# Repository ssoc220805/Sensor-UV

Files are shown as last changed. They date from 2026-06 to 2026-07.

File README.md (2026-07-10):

# Centinela UV — Sistema de Monitoreo de Radiación Ultravioleta

Centinela UV es un dispositivo IoT basado en **ESP32-S3** y sensor **GY-ML8511** que mide la radiación ultravioleta, avisa el nivel de riesgo con un **LED RGB**, envía cada lectura a un **servidor web en Hostinger** donde queda guardada, y manda una **alerta por Telegram** cuando el índice UV sube a un nivel peligroso.

Proyecto desarrollado para el curso **TEI201 — Taller de Diseño en Ingeniería**, Universidad Adolfo Ibáñez.

---

## Integrantes

- Leo Castro
- Sara Orellana
- Cristian Yañez

---

## El problema

Las personas que pasan tiempo al aire libre no tienen una forma directa de saber qué tan intensa es la radiación ultravioleta a la que están expuestas, ni cuándo deberían protegerse. La información disponible suele ser general (el pronóstico de la ciudad) y no refleja las condiciones del lugar exacto donde está la persona.

Centinela UV entrega una medición local y en tiempo real de la radiación UV, junto con una recomendación clara de protección según el nivel detectado.

---

## Qué hace el sistema

El sistema cumple el ciclo completo de un dispositivo IoT:

1. **Captura.** El sensor GY-ML8511 entrega un voltaje proporcional a la radiación UV. El ESP32-S3 lo lee con su conversor analógico-digital y lo transforma en un índice UV.
2. **Almacena.** Cada 3 segundos el ESP32 envía la lectura por WiFi a un script `guardar.php` alojado en Hostinger, que la guarda de forma permanente. Los datos siguen ahí aunque el dispositivo se apague.
3. **Visualiza.** El dashboard web muestra el índice UV actual, la recomendación de protección y el resumen del día (máximo, mínimo y promedio) con un gráfico.
   → https://lightskyblue-zebra-707371.hostingersite.com/
4. **Decide.** El LED RGB cambia de color según el nivel de riesgo, y si el índice supera el umbral el sistema **manda una alerta a Telegram** para que el usuario se entere aunque no esté mirando ni el dispositivo ni la página.

---

## Arquitectura

```
Sensor GY-ML8511  →  ESP32-S3  →  WiFi  →  Hostinger (guardar.php)  →  Dashboard web
                          │
                          ├──→  LED RGB (aviso local inmediato)
                          └──→  API de Telegram (alerta al celular)
```

El ESP32 se conecta a una red WiFi existente (durante las pruebas usamos el hotspot de un celular). No sirve la página web por sí mismo: la página está alojada en Hostinger, y por eso se puede abrir desde cualquier lugar con internet, no solo estando al lado del dispositivo.

---

## Niveles de riesgo

El firmware clasifica el índice UV en tres niveles:

| Índice UV | Nivel | Color del LED | Alerta Telegram | Recomendación |
|---|---|---|---|---|
| 0.0 – 2.9 | BAJO | Verde | No | No se requiere protección especial |
| 3.0 – 5.9 | MODERADO | Amarillo | Aviso | Usar bloqueador y lentes de sol |
| 6.0 o más | ALTO | Rojo | Alerta | Buscar sombra, usar bloqueador, sombrero y lentes |

Los cortes en 3 y 6 vienen de la tabla oficial del Índice UV de la OMS. Agrupamos las categorías "alto", "muy alto" y "extremo" en un solo nivel ALTO porque la acción recomendada para el usuario es la misma: protegerse.

Para no llenar de mensajes el celular, el sistema solo envía una alerta **cuando el nivel cambia** (por ejemplo, de BAJO a MODERADO) y respeta un tiempo de espera entre alertas del mismo tipo.

---

## Componentes

| Componente | Cantidad | Especificación | Función |
|---|---|---|---|
| ESP32-S3 DevKitC-1 | 1 | WiFi 2.4 GHz, doble núcleo | Lee el sensor, controla el LED y envía los datos |
| Sensor UV GY-ML8511 | 1 | Salida analógica, 280–390 nm | Medición de radiación ultravioleta |
| LED RGB | 1 | Cátodo común, 5 mm | Indicación visual del nivel de riesgo |
| Resistencias | 3 | 220 Ω, 1/4 W | Limitan la corriente de cada canal del LED |
| Batería LiPo | 1 | 3.7 V, ~1200 mAh | Alimentación autónoma |
| Controlador Li-Po Rider Pro | 1 | Carga solar/USB, salida 5 V | Gestiona la carga y alimenta el ESP32 |
| Panel solar | 1 | 5 V, ~1 W | Recarga la batería |
| Mini protoboard | 1 | — | Montaje sin soldar |
| Cables Dupont | 1 set | 20 cm | Conexiones |

El detalle con costos está en [`hardware/Documentacion_Hardware.md`](hardware/Documentacion_Hardware.md).

---

## Conexiones

| Señal | Pin del ESP32-S3 | Nota |
|---|---|---|
| Sensor UV — VCC | 3.3 V | Alimentación del sensor |
| Sensor UV — GND | GND | Tierra común |
| Sensor UV — OUT | **GPIO4** | Entrada analógica (ADC1) |
| LED Rojo | **GPIO40** | Con resistencia de 220 Ω |
| LED Verde | **GPIO39** | Con resistencia de 220 Ω |
| LED Azul | **GPIO38** | Con resistencia de 220 Ω |
| LED — pata común | GND | LED de cátodo común |
| Batería LiPo | Li-Po Rider Pro (BAT) | Conector JST |
| Panel solar | Li-Po Rider Pro (SOLAR) | Entrada de carga solar |
| Li-Po Rider Pro — salida 5 V | VIN del ESP32-S3 | Alimenta todo el sistema |

Estos son los pines que usa el código en `firmware/centinela_uv2.ino`. La tabla, el esquemático y el código dicen lo mismo.

---

## Estructura del repositorio

```
centinela-uv-tei201/
├── README.md
├── FUENTES.md
├── .gitignore
├── firmware/
│   ├── centinela_uv2.ino          Código del ESP32
│   └── config_ejemplo.h           Plantilla de credenciales (sin claves reales)
├── backend/
│   ├── guardar.php                Recibe y guarda cada lectura
│   ├── test.php                   Activa el modo demostración
│   └── index.html                 Dashboard web
├── hardware/
│   ├── Documentacion_Hardware.md
│   ├── esquematico.png
│   └── fotos/
├── diseño-3d/
│   ├── Modelado_3D_rehechov2.f3d
│   ├── soporte__defin_.f3d
│   ├── planos.pdf
│   └── renders/
├── testing/
│   ├── Protocolo_de_pruebas.md
│   ├── Resultados.md
│   ├── datos/lecturas_23-06-2026.csv
│   └── evidencia/                 Capturas del bot de Telegram y del dashboard
└── docs/
    └── presentacion.pdf
```

---

## Cómo cargar el firmware

1. Instalar el [Arduino IDE](https://www.arduino.cc/en/software) y agregar el soporte para placas ESP32 desde el Gestor de Tarjetas.
2. Abrir `firmware/centinela_uv2.ino`.
3. En **Herramientas → Placa**, seleccionar **ESP32S3 Dev Module**.
4. Crear un archivo `config.h` a partir de `config_ejemplo.h` y completar la red WiFi, la clave de la API y las credenciales del bot de Telegram.
5. Conectar la placa por USB, seleccionar el puerto y subir el código.
6. Abrir el Monitor Serial a **115200 baudios** para ver las lecturas y confirmar que la respuesta del servidor sea `200`.

El firmware usa `WiFi.h`, `WiFiClientSecure.h` y `HTTPClient.h`, que vienen incluidas con el núcleo de ESP32. No hay que instalar librerías externas.

### Sobre las credenciales

La red WiFi, la clave de la API y el token del bot de Telegram **no se suben al repositorio**. Van en `config.h`, que está listado en `.gitignore`. Si alguien publica un token de Telegram por accidente, hay que revocarlo de inmediato con @BotFather y generar uno nuevo.

---

## Cómo usar el dashboard

El dashboard está alojado en Hostinger, así que se abre desde cualquier navegador con internet: no hace falta estar cerca del dispositivo.

1. Encender el dispositivo y verificar que se conecte al WiFi (el Monitor Serial muestra la IP).
2. Abrir https://lightskyblue-zebra-707371.hostingersite.com/
3. La página muestra la última lectura, la recomendación de protección y el gráfico del día.

Las lecturas quedan guardadas en el servidor, así que el histórico sigue disponible aunque el ESP32 se apague o se reinicie.

---

## Alertas de Telegram

El bot **Centinela UV Bot** envía tres tipos de mensaje:

- `Sistema Monitor UV encendido.` — cada vez que el dispositivo arranca y logra conectarse.
- `Aviso: UV moderado. Indice X` — cuando el índice pasa de BAJO a MODERADO.
- `ALERTA UV ALTO. Indice X` — cuando el índice llega al nivel ALTO.

Existe además un **modo demostración**: el ESP32 consulta cada 6 segundos un archivo `test.php` en el servidor, y si este devuelve `1`, el dispositivo fuerza el estado ALTO durante 8 segundos y manda el mensaje `PRUEBA: alerta de UV ALTO.`. Esto nos permite mostrar la alerta funcionando en la presentación sin depender de que haya sol. Los mensajes que empiezan con `PRUEBA:` corresponden a este modo, no a una medición real.

---

## Limitaciones conocidas

- La conversión de voltaje a índice UV usa la relación aproximada del ML8511 (0.99 V ≈ 0, 2.8 V ≈ 15). No fue calibrada contra un medidor UV de referencia, así que el valor absoluto puede tener error; lo que sí validamos es que el sensor responde correctamente a los cambios de luz.
- El firmware envía dos campos `temp` y `hum` que siempre valen 0, porque quedaron de una versión anterior del proyecto que contemplaba un sensor de temperatura. El sistema no mide temperatura ni humedad.
- El sistema necesita una red WiFi disponible. Si se cae la conexión, el dispositivo sigue midiendo y encendiendo el LED, pero no guarda ni alerta.

---

## Declaración de fuentes

El uso de librerías, código externo y herramientas de inteligencia artificial está documentado en [`FUENTES.md`](FUENTES.md), de acuerdo con el código de honor de la Universidad Adolfo Ibáñez.

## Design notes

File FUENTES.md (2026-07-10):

# Declaración de Fuentes e Inteligencia Artificial

Este documento declara las librerías, los servicios externos, el código externo y las herramientas de inteligencia artificial que usamos para desarrollar **Centinela UV**. La idea es ser transparentes sobre qué partes del trabajo se apoyaron en recursos externos y dejar claro que entendemos todo el código que forma parte del sistema, de acuerdo con el código de honor de la Universidad Adolfo Ibáñez.

Los números de línea corresponden al archivo `firmware/centinela_uv2.ino`.

---

## 1. Librerías utilizadas

| Librería | Versión | Para qué la usamos | Fuente |
|---|---|---|---|
| `WiFi.h` | core ESP32 `<completar>` | Conectar el ESP32-S3 a la red WiFi en modo estación (STA) | https://github.com/espressif/arduino-esp32 |
| `WiFiClientSecure.h` | core ESP32 `<completar>` | Abrir la conexión HTTPS hacia Hostinger y hacia la API de Telegram | https://github.com/espressif/arduino-esp32 |
| `HTTPClient.h` | core ESP32 `<completar>` | Hacer las peticiones POST y GET al servidor y al bot | https://github.com/espressif/arduino-esp32 |

Las tres librerías vienen incluidas con el núcleo de ESP32 para Arduino, así que no fue necesario instalar nada aparte. La versión es la del núcleo instalado y se revisa en **Arduino IDE → Herramientas → Placa → Gestor de Tarjetas → esp32**.

> Nota para el equipo: completar los tres campos de versión antes de entregar.

---

## 2. Servicios externos utilizados

| Servicio | Para qué lo usamos |
|---|---|
| Hostinger (hosting PHP) | Aloja `guardar.php`, que recibe las lecturas y las almacena, y el dashboard web |
| API de Telegram Bot | Envía las alertas al celular cuando el índice UV sube de nivel |

---

## 3. Código externo adaptado

No copiamos código completo desde tutoriales, foros ni repositorios de otras personas. Usamos como referencia conceptual los ejemplos oficiales del núcleo de ESP32 para conexión WiFi y para peticiones HTTP, y la documentación de la API de Telegram para el formato de la URL de `sendMessage`:

- Ejemplos WiFi y HTTPClient: https://github.com/espressif/arduino-esp32/tree/master/libraries
- API de Telegram: https://core.telegram.org/bots/api#sendmessage

Las partes del código que no escribimos desde cero las desarrollamos con ayuda de inteligencia artificial, y están declaradas en la sección siguiente.

---

## 4. Uso de Inteligencia Artificial

### 4.1 Lectura del sensor: `leerUV()` (líneas 71–89)

- **Herramienta:** Claude (junio 2026).
- **Prompt utilizado:** "Escribe una función en C++ para Arduino que lea un sensor analógico ML8511 con el ADC del ESP32-S3 y convierta el voltaje en índice UV."
- **Cómo lo adaptamos:** cambiamos la lectura única por el promedio de 5 muestras seguidas con 1 ms de separación, para reducir el ruido del ADC. Ajustamos la conversión a la relación del GY-ML8511 (0.99 V ≈ índice 0, 2.8 V ≈ índice 15) y agregamos una saturación entre 0 y 20 para descartar valores imposibles.
- **Comprensión:** entendemos que `analogRead()` devuelve un número entre 0 y 4095 porque configuramos 12 bits de resolución; ese número se multiplica por `3.3/4095` para obtener el voltaje real del pin; y `mapFloat()` hace una interpolación lineal entre los dos puntos de referencia del sensor. Verificamos el comportamiento en el Monitor Serial tapando y destapando el sensor.

### 4.2 Control del LED RGB: `setColor()` y clasificación en el `loop()` (líneas 59–69 y 227–260)

- **Herramienta:** Claude y Gemini (junio 2026).
- **Para qué:** apoyo para escribir la función que enciende los tres canales del LED y la lógica que decide el color según el índice UV.
- **Cómo lo adaptamos:** definimos nosotros los cortes en 3.0 y 6.0 a partir de la tabla del Índice UV de la OMS, agrupando "alto", "muy alto" y "extremo" en un solo nivel ALTO. Agregamos la constante `ANODO_COMUN` para que la función sirva con LED de ánodo o de cátodo común (usamos cátodo común, `false`).
- **Comprensión:** entendemos que el LED se controla con tres salidas digitales independientes y que el color se forma combinándolas (verde = solo G, amarillo = R + G, rojo = solo R). Si el LED fuera de ánodo común, la lógica se invierte, y por eso la función niega los tres valores.

### 4.3 Envío de datos al servidor: `enviarDato()` (líneas 119–152)

- **Herramienta:** Claude (junio 2026).
- **Para qué:** apoyo para armar la petición HTTPS hacia el script `guardar.php` en Hostinger.
- **Cómo lo adaptamos:** definimos el formato del cuerpo (`key`, `uv`, `temp`, `hum`) para que coincidiera con lo que espera nuestro `guardar.php`, y agregamos una verificación de conexión WiFi que intenta reconectar antes de enviar.
- **Comprensión:** entendemos que se abre un cliente seguro, se envía la información como un formulario (`x-www-form-urlencoded`) mediante POST, y que el servidor responde con un código HTTP; el 200 confirma que el dato quedó guardado. Usamos `client.setInsecure()` porque no cargamos el certificado raíz en el ESP32; sabemos que eso significa que no se valida la identidad del servidor, y es una limitación aceptable para un prototipo académico.

### 4.4 Alertas de Telegram: `enviarTelegram()` (líneas 154–176) y la lógica de aviso en el `loop()` (líneas 261–277)

- **Herramienta:** Claude (junio 2026).
- **Prompt utilizado:** "Cómo enviar un mensaje desde un ESP32 a un bot de Telegram usando HTTPClient, sin librerías externas."
- **Cómo lo adaptamos:** reemplazamos los espacios y saltos de línea del mensaje por `%20` y `%0A` para que la URL sea válida. Sobre esa base, nosotros escribimos la lógica de cuándo alertar: el mensaje se manda **solo cuando el nivel cambia** (comparando `nivel` con `nivelAnterior`) y respetando un tiempo de espera (`COOLDOWN_TG`), para no llenar el chat de mensajes repetidos cuando el índice oscila alrededor de un umbral.
- **Comprensión:** entendemos que la API de Telegram recibe el token del bot y el `chat_id` dentro de la URL y devuelve un código HTTP; que `nivelAnterior` es lo que evita que se repita la alerta en cada ciclo del `loop`; y que el cooldown es una segunda protección para el caso en que el índice cruce el umbral varias veces seguidas.

### 4.5 Modo demostración: `revisarPrueba()` (líneas 178–200)

- **Herramienta:** Claude (junio 2026).
- **Para qué:** necesitábamos poder mostrar la alerta funcionando durante la presentación sin depender de que hubiera sol.
- **Cómo lo adaptamos:** el ESP32 consulta cada 6 segundos un archivo `test.php` del servidor; si devuelve `1`, guarda un tiempo límite en `pruebaHasta` y manda el mensaje `PRUEBA: alerta de UV ALTO.`. Durante los 8 segundos siguientes el `loop` fuerza el estado ALTO y el LED rojo.
- **Comprensión:** entendemos que esta función **no mide nada**: fuerza el estado. Por eso los mensajes que empiezan con `PRUEBA:` no corresponden a mediciones reales, y por eso en las capturas se ve un `ALERTA UV ALTO. Indice 0.0` justo después de una prueba: el nivel se forzó aunque el sensor estuviera leyendo 0. Lo declaramos explícitamente para no confundir simulación con medición.

### 4.6 Backend: `guardar.php`, `test.php` y dashboard `index.html`

- **Herramienta:** Claude (junio 2026).
- **Para qué:** generar el script PHP que recibe cada lectura y la guarda de forma persistente en el hosting, y la página web que muestra el valor actual, la recomendación de protección y el gráfico del día con máximo, mínimo y promedio.
- **Cómo lo adaptamos:** definimos la clave de API para que el servidor rechace peticiones que no vengan de nuestro dispositivo; mantuvimos los rangos y colores que definimos como equipo; y agregamos un modo de demostración en la página para poder mostrarla completa en la presentación.
- **Comprensión:** entendemos que el ESP32 hace un POST con los datos, el PHP los valida contra la clave y los agrega al registro, y la página lee ese registro para dibujar el gráfico y calcular los estadísticos del día.

### 4.7 Estructura del README y de este archivo

- **Herramienta:** Claude (junio 2026).
- **Para qué:** generar la estructura base de `README.md` y de este `FUENTES.md`.
- **Cómo lo adaptamos:** el contenido técnico (pines, niveles, decisiones de diseño, resultados de las pruebas) lo escribimos nosotros a partir del sistema que efectivamente construimos.

### 4.8 Orientación general del proyecto

- **Herramienta:** Claude y Gemini.
- **Para qué:** pedir orientación sobre cómo avanzar en el proyecto, la organización del repositorio y dudas puntuales durante el desarrollo.
- **Nota:** este apoyo fue de orientación al proceso. Las decisiones de diseño, la selección de componentes, el montaje físico y el contenido final del proyecto los definimos nosotros como grupo.

---

## 5. Declaración final

Declaramos que las herramientas externas y la inteligencia artificial se usaron como apoyo para acelerar el desarrollo, la depuración y la documentación. Las decisiones técnicas, la integración física, las pruebas y la adaptación al problema fueron realizadas por el equipo. Todos los integrantes podemos explicar qué hace cada función del código y por qué está donde está.

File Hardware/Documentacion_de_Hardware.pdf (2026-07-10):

## Documentación de Hardware — Centinela UV

TEI201 · Taller de Diseño en Ingeniería · Universidad Adolfo Ibáñez Leo Castro · Sara Orellana · Cristian Yañez

### 1. Descripción general

Centinela UV es un dispositivo portátil que mide la radiación ultravioleta y avisa el nivel de riesgo de tres formas: un LED RGB que cambia de color, una página web que muestra el valor y una recomendación, y una alerta por Telegram cuando el índice UV es alto.

Está pensado para usarse al aire libre. Por eso se alimenta con una batería recargable mediante un panel solar, y no necesita estar enchufado.

### 2. Selección y justificación de componentes

Elegimos cada componente pensando en que el dispositivo funcionara de forma autónoma al aire libre, fuera fácil de armar y se mantuviera barato.

Componente | Por qué lo elegimos
ESP32-S3 DevKitC-1 | Trae WiFi 2.4 GHz integrado, así podemos enviar los datos al servidor y las alertas a Telegram sin hardware adicional. Su ADC de 12 bits es suficiente para leer la salida analógica del sensor.
Sensor UV GY-ML8511 | Cubre el rango UVA/UVB (280–390 nm), que es el que afecta a la piel. Entrega una salida analógica lineal, fácil de leer con el ADC del ESP32. Es común y económico.
LED RGB (cátodo común) | Permite comunicar el nivel de riesgo con un color, de un vistazo, sin tener que mirar la pantalla ni el celular.
Resistencias 220 Ω | Limitan la corriente de cada canal del LED para que no se queme. Con 3.3 V y un LED de caída ~2 V, la corriente queda cerca de 6 mA por canal: suficiente brillo, bajo consumo.
Batería LiPo 3.7 V | Permite que el dispositivo funcione sin estar enchufado, que es la idea al usarlo al aire libre.
Controlador Li-Po Rider Pro | Maneja la carga de la batería desde el panel solar, protege la celda y entrega 5 V estables al ESP32. Sin él, conectar el panel directo a la batería sería inseguro.
Panel solar 5 V ~1 W | Recarga la batería con el sol. Como el dispositivo se usa justamente cuando hay sol, la fuente de energía coincide con el momento de uso.
Mini protoboard | Permite armar y cambiar conexiones sin soldar, lo que apoya el diseño para la reparación.
Cables Dupont | Conexiones desmontables entre el sensor, el LED y el ESP32.

### 3. Consumo y autonomía

Valores típicos de hoja de datos. Sirven para estimar la autonomía; conviene verificarlos con multímetro.

Elemento | Consumo típico
ESP32-S3 con WiFi activo | ~100 mA promedio (picos de hasta ~350 mA al transmitir)
Sensor GY-ML8511 | ~0,3 mA
LED RGB (1 canal encendido) | ~6 mA
Total estimado | ~110 mA promedio

Con una batería de 1200 mAh:

Autonomía ≈ 1200 mAh / 110 mA ≈ 11 horas de uso continuo

El panel solar de 1 W entrega aproximadamente 200 mA a 5 V con sol directo, es decir más de lo que consume el sistema. En condiciones de buena luz el panel alcanza para alimentar el dispositivo y además recargar la batería, que es exactamente el escenario de uso del proyecto.

### 4. Lista de materiales (BOM)

Componente | Cant. | Especificación | Precio unit. (CLP) | Subtotal (CLP)
ESP32-S3 DevKitC-1 | 1 | WiFi 2.4 GHz, doble núcleo | $14.990 | $14.990

Sensor UV GY-ML8511 | 1 | Analógico, 280–390 nm | $20.000 | $20.000
LED RGB | 1 | Cátodo común, 5 mm | $800 | $800
Resistencia 220 Ω | 3 | 1/4 W | $100 | $300
Batería LiPo 3.7 V | 1 | Recargable, ~1200 mAh | $7.000 | $7.000
Controlador Li-Po Rider Pro | 1 | Carga solar/USB, salida 5 V | $18.000 | $18.000
Panel solar | 1 | 5 V, ~1 W | $6.000 | $6.000
Mini protoboard | 1 | 400 puntos | completar | completar
Cables Dupont (set) | 1 | 20 cm | $2.500 | $2.500
Filamento de impresión | — | Carcasa del encapsulado | completar | completar
TOTAL | | | | $69.590 + carcasa

Precios referenciales tomados de tiendas chilenas (MCI, Altronics, MaxElectronica, Makers) en junio de 2026, con IVA aproximado.

Nota para el equipo: completar el precio de la mini protoboard y del filamento, y recalcular el total antes de entregar.

### 5. Conexiones del circuito

El sensor entrega su señal a una entrada analógica del ESP32, el LED se controla con tres pines (cada uno con su resistencia) y la energía viene de la batería junto al panel solar a través del Li-Po Rider Pro.

Desde | Hacia (ESP32-S3) | Notas
Sensor UV — VCC | 3.3 V | Alimentación del sensor
Sensor UV — GND | GND | Tierra común
Sensor UV — OUT (SIG) | GPIO4 | Entrada analógica (ADC1), atenuación 11 dB
LED Rojo | GPIO40 | Con resistencia de 220 Ω
LED Verde | GPIO39 | Con resistencia de 220 Ω
LED Azul | GPIO38 | Con resistencia de 220 Ω
LED — pata común | GND | LED de cátodo común
Batería LiPo | Li-Po Rider Pro (BAT) | Conector JST
Panel solar | Li-Po Rider Pro (SOLAR) | Entrada de carga solar
Li-Po Rider Pro — salida 5 V | VIN del ESP32-S3 | Alimenta todo el sistema

Estos pines son exactamente los que declara el firmware:

const int PIN_UV = 4; // OUT del sensor (ADC)
const int PIN_R = 40;
const int PIN_G = 39;
const int PIN_B = 38;

Tierra común: todos los negativos del sistema comparten GND (ESP32, sensor, pata común del LED, salida negativa del Li-Po Rider Pro y negativo de la batería). Sin tierra común, la lectura del ADC no es confiable.

### 6. Esquema del sistema

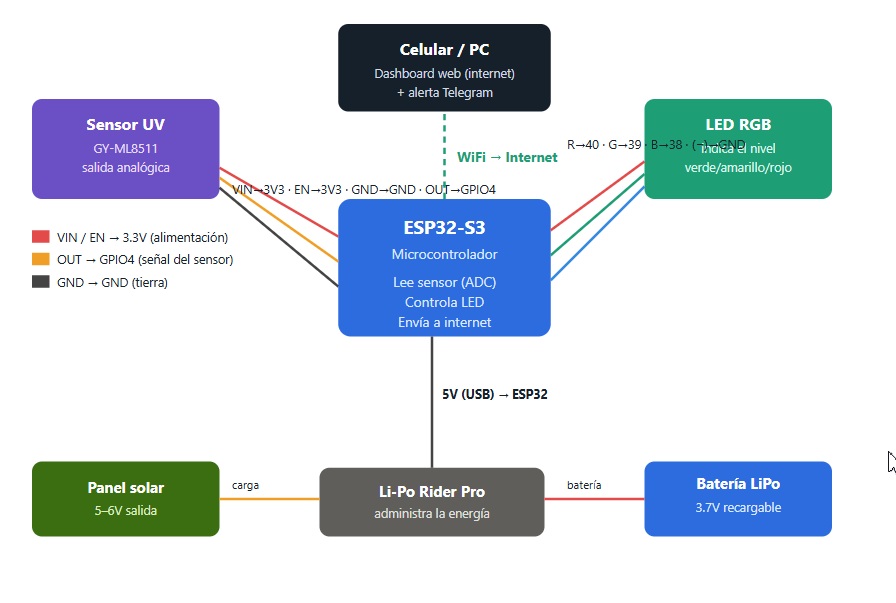
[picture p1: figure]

Figura 1. Diagrama de bloques. El sensor UV entrega su señal analógica al GPIO4 del ESP32-S3, que controla el LED RGB (GPIO40/39/38), envía las lecturas por WiFi al dashboard web y dispara las alertas de Telegram. La energía viene del panel solar y la batería LiPo, administradas por el Li-Po Rider Pro, que entrega 5 V al ESP32.

El diagrama de bloques muestra qué se conecta con qué y hacia dónde viajan los datos, pero no reemplaza al esquemático eléctrico: no dibuja las tres resistencias de 220 Ω ni el riel de tierra común. El esquemático completo se entrega aparte, en hardware/esquematico.png.

### 7. Montaje físico

El prototipo está montado sobre una mini protoboard, con el ESP32-S3, el sensor UV y el LED RGB conectados mediante cables Dupont. La batería y el panel solar se conectan al Li-Po Rider Pro, que alimenta todo el sistema con 5 V.

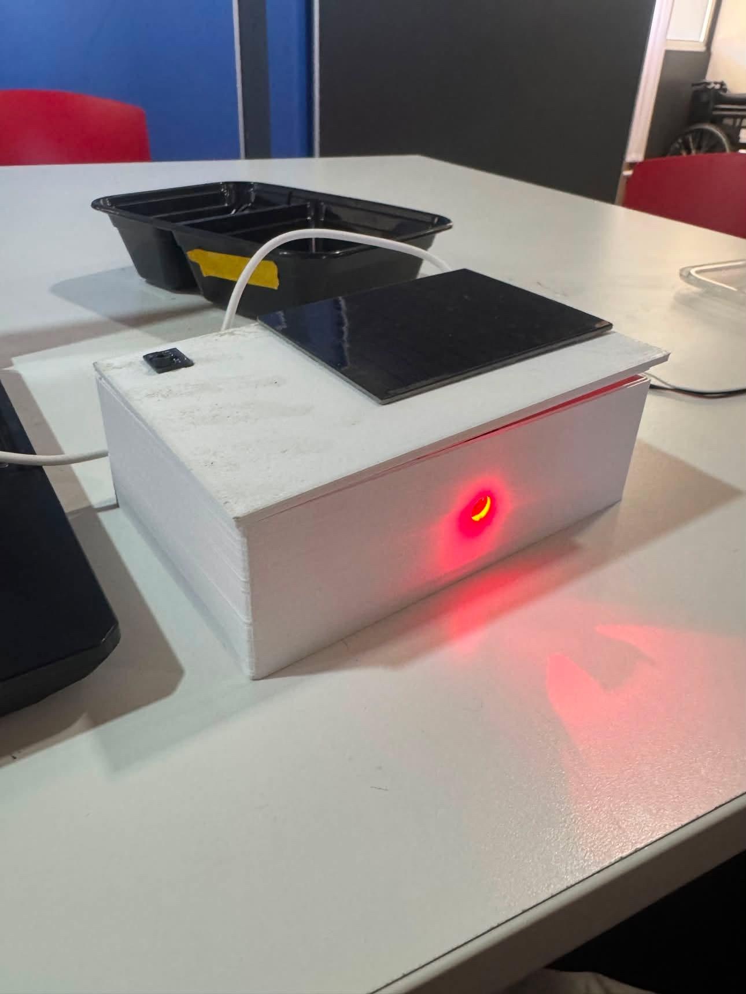
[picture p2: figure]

Figura 2. Vista exterior, LED en rojo (nivel ALTO). El panel solar va montado sobre la tapa. El LED atraviesa la cara frontal, de modo que el nivel de riesgo se ve sin abrir la caja.

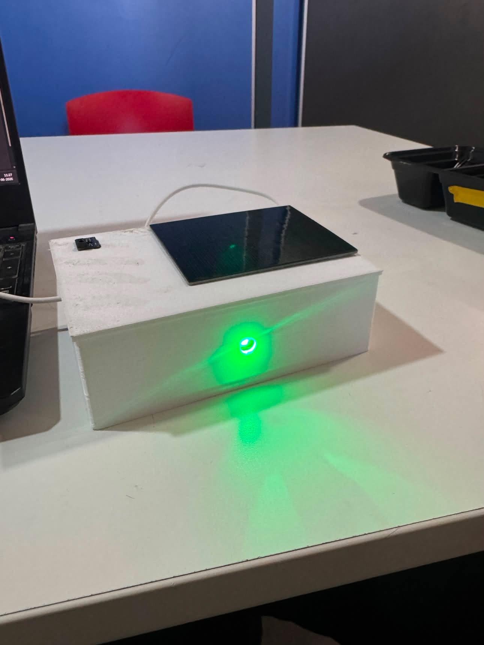
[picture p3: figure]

Figura 3. Vista exterior, LED en verde (nivel BAJO). El mismo dispositivo indicando radiación baja. El color es visible a distancia y en exteriores.

Figura 4. Vista interior con la tapa abierta. Se ven la batería LiPo con su soporte a la izquierda, el ESP32-S3 a la derecha sobre su base, y el Li-Po Rider Pro en la parte inferior. Todos los componentes están conectados con cables Dupont y sujetos a soportes impresos: ninguno está pegado ni soldado de forma permanente. El puerto USB queda accesible para reprogramar el ESP32 sin desmontar nada.

### 8. Diseño para la reparación

El encapsulado está pensado para poder repararse en el tiempo sin romperlo. Las decisiones principales:

Tapa desmontable con tornillos, no pegada. Se abre para acceder a todos los componentes.
Componentes conectados, no soldados ni pegados: cualquiera de los cinco módulos (ESP32, sensor, LED, batería, Li-Po Rider Pro) se puede reemplazar de forma individual en terreno.
Sensor UV alejado de la batería, para que el calor de la celda no afecte la medición.
Ranuras laterales que dejan salir el calor del ESP32 y del regulador.
Puerto USB accesible desde el exterior para reprogramar sin desarmar la caja.

El volumen general del encapsulado es una caja de 16 × 10 × 5 cm.

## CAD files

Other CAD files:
Modelo 3D/Modelado 3D rehechov2.f3d
Modelo 3D/soporte (defin).f3d

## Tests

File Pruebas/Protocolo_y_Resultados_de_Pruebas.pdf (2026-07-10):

### Protocolo de Pruebas, Resultados y Validación

Centinela UV · TEI201 · Universidad Adolfo Ibáñez Leo Castro · Sara Orellana · Cristian Yañez

### 1. Objetivo general

Comprobar que Centinela UV funciona como un sistema IoT completo, es decir, que:

1. mide radiación ultravioleta real y no entrega valores al azar,
2. clasifica correctamente esa medición en un nivel de riesgo,
3. comunica el nivel con el LED RGB,
4. envía las lecturas al servidor y estas quedan guardadas,
5. avisa por Telegram cuando el índice sube de nivel,
6. muestra la información de forma interpretable en el dashboard.

### 2. Equipo y condiciones

Todas las pruebas se hicieron con el prototipo completo: ESP32-S3 DevKitC-1, sensor UV GY-ML8511, LED RGB de cátodo común con resistencias de 220 Ω, batería LiPo 3.7 V y Li-Po Rider Pro, hotspot WiFi de un celular, servidor Hostinger (guardar.php, test.php, dashboard) y el bot de Telegram "Centinela UV Bot".

Umbrales usados en todas las pruebas:

Índice UV | Nivel | LED | Mensaje de Telegram
0.0 – 2.9 | BAJO | Verde | —
3.0 – 5.9 | MODERADO | Amarillo | Aviso
6.0 o más | ALTO | Rojo | Alerta

Aclaración sobre las simulaciones. No siempre tuvimos sol disponible a la hora de probar. Por eso distinguimos dos tipos de prueba y lo señalamos en cada resultado:

Prueba real: el sensor midiendo radiación solar al aire libre.
Simulación: el sensor expuesto a una fuente de luz artificial cercana, o bien el modo demostración, en el que test.php fuerza el estado ALTO durante 8 segundos sin medir nada. Los mensajes que empiezan con PRUEBA: corresponden a este modo.

### 3. Pruebas

Prueba 1 — Lectura del sensor (real)

Objetivo: comprobar que el sensor mide radiación ultravioleta de verdad: que en condiciones de poca luz el valor se mantenga cerca de cero, y que suba cuando recibe más luz.

Condiciones: 23 de junio de 2026, ~18:05 hrs, en un balcón, al atardecer. Radiación esperada baja. ESP32 conectado por USB a un computador para registrar las lecturas.

Procedimiento:

1. Conectar el circuito completo (sensor, LED, ESP32).
2. Conectar el ESP32 al computador por USB.
3. Cargar el firmware y abrir el Monitor Serial.
4. Dejar el sensor quieto en el balcón y registrar las lecturas durante poco más de dos minutos.
5. Al final, acercar el sensor a una fuente de más luz para ver si el valor reacciona.

Criterio de éxito: en una hora de poca radiación el valor se mantiene cercano a cero, y al recibir más luz sube de forma clara y rápida.

Prueba 2 — Umbrales y color del LED (simulación)

Objetivo: verificar que los tres niveles se activan en los cortes correctos y que el LED muestra el color que corresponde.

Procedimiento:

1. Con el sensor en sombra, verificar índice bajo 3.0 y LED verde.
2. Acercar gradualmente una fuente de luz hasta que el índice quede entre 3.0 y 5.9; verificar LED amarillo.
3. Acercar más la fuente hasta superar 6.0; verificar LED rojo.
4. Alejar la fuente y comprobar que el LED vuelve a amarillo y luego a verde.
5. Contrastar el color observado con el valor impreso en el Monitor Serial.

Criterio de éxito: el color del LED coincide siempre con el nivel que imprime el Monitor Serial, y los cambios ocurren en 3.0 y 6.0.

Prueba 3 — Alertas de Telegram (real) y (simulación)

Objetivo: comprobar que el bot avisa cuando el índice sube de nivel, y que no repite la alerta en cada ciclo.

Procedimiento:

1. Encender el dispositivo y verificar que llegue el mensaje Sistema Monitor UV encendido.
2. Subir el índice hasta MODERADO y verificar que llegue un Aviso.
3. Subir hasta ALTO y verificar que llegue una ALERTA.
4. Mantener el índice en ALTO durante un minuto y confirmar que no llegan mensajes repetidos.
5. Bajar el índice a BAJO y volver a subirlo; confirmar que llega una alerta nueva.

Criterio de éxito: llega un mensaje por cada cambio de nivel, con el índice correcto, y el chat no se llena de mensajes repetidos mientras el nivel se mantiene.

Prueba 4 — Envío y persistencia de los datos

Objetivo: comprobar que cada lectura llega al servidor y que sigue ahí después de apagar el dispositivo.

Procedimiento:

1. Encender el dispositivo con WiFi disponible.
2. Verificar en el Monitor Serial que la respuesta del servidor sea Dashboard HTTP: 200.
3. Dejarlo tomando datos durante unos minutos.
4. Apagar el ESP32.
5. Recargar el dashboard desde otro dispositivo y comprobar que las lecturas anteriores siguen visibles.

Criterio de éxito: el servidor responde 200 en cada envío y los datos permanecen disponibles después de apagar y reiniciar el ESP32.

Prueba 5 — Modo demostración

Objetivo: verificar que podemos disparar una alerta de UV ALTO a voluntad, para la presentación.

Procedimiento:

1. Activar test.php en el servidor.
2. Esperar hasta 6 segundos (intervalo de consulta del ESP32).
3. Verificar que llegue el mensaje PRUEBA: alerta de UV ALTO.
4. Verificar que el LED se ponga rojo durante 8 segundos y luego vuelva al color que corresponde a la medición real.

Criterio de éxito: la alerta de prueba se dispara de forma confiable y el sistema vuelve solo a su estado real. Este modo no mide radiación: fuerza el estado.

Prueba 6 — Dashboard

Objetivo: verificar que el dashboard convierte los datos en información interpretable.

Procedimiento:

1. Abrir el dashboard con el dispositivo encendido.

2. Comprobar que el valor mostrado coincide con el del Monitor Serial.
3. Comprobar que el borde de color y la recomendación cambian con el nivel.
4. Revisar que el gráfico del día y los valores máximo, mínimo y promedio se actualicen.

Criterio de éxito: el dashboard muestra el valor actual, una recomendación coherente con ese valor y un resumen del día que permite ver la evolución de la radiación.

### 4. Resultados — Prueba 1 (medición real)

Registramos 57 lecturas en poco más de dos minutos (18:05:49 – 18:07:52), el 23 de junio de 2026, en un balcón al atardecer.

La prueba tiene dos fases: las primeras 55 lecturas con el sensor quieto midiendo la luz del ambiente, y las 2 últimas después de acercarlo a una fuente de más luz. Los separamos porque mezclarlos distorsiona el promedio.

Métrica | Fase ambiente (55 lecturas) | Serie completa (57)
Promedio | 0,34 | 0,44
Máximo | 1,2 (18:06:54) | 3,9 (18:07:52)
Mínimo | 0,0 | 0,0
Mediana | 0,3 | 0,3
Nivel | BAJO en las 55 | BAJO salvo la última

Durante la fase ambiente los valores se mantuvieron muy bajos, todos dentro del nivel BAJO, que es exactamente lo que se espera a esa hora. El valor 0,0 aparece 12 veces, siempre de forma aislada entre lecturas positivas.

En los últimos 4 segundos, al exponer el sensor a más luz, el valor subió de forma clara:

18:07:48 → 0,3 | (ambiente)
18:07:50 → 2,3 | (expuesto)
18:07:52 → 3,9 | (expuesto, nivel MODERADO)

Un salto de más de diez veces el promedio ambiental en dos lecturas consecutivas.

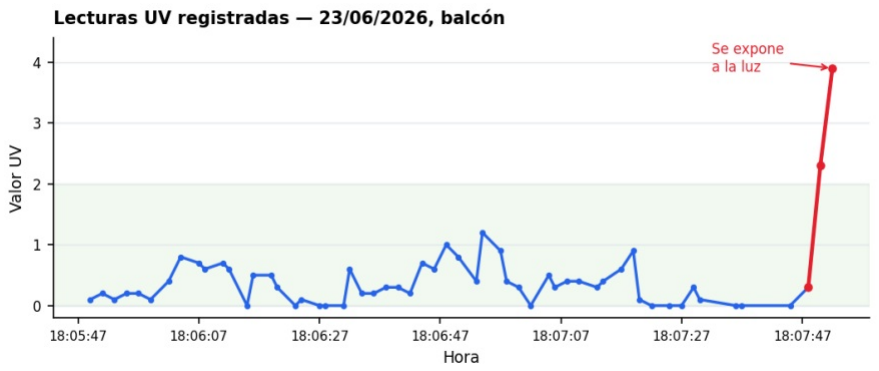
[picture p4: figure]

Figura 1. Las 57 lecturas registradas. Se observa una banda de ruido baja durante dos minutos y, al final, la subida vertical al exponer el sensor a la luz.

Conclusión: el sensor responde a la radiación real y no entrega datos sin sentido. La prueba cumple el criterio de éxito.

Sobre el registro: las lecturas se guardaron cada 2 o 3 segundos, pero hay tres huecos más largos (18:07:30 → 18:07:36 → 18:07:45). Corresponden a lecturas que no alcanzaron a registrarse mientras el ESP32 transmitía por WiFi. No afecta la conclusión, pero muestra que el registro no es de intervalo constante.

Los datos crudos están en testing/datos/lecturas_23-06-2026.csv, con una columna fase que distingue las lecturas de ambiente de las de exposición.

### 5. Resultados — Pruebas 2 y 3 (umbrales, LED y Telegram)

Estas pruebas se hicieron combinando medición real (con sol, durante la tarde) y simulación (con luz artificial cercana al sensor, y con el modo demostración), porque no siempre teníamos sol disponible a la hora de probar.

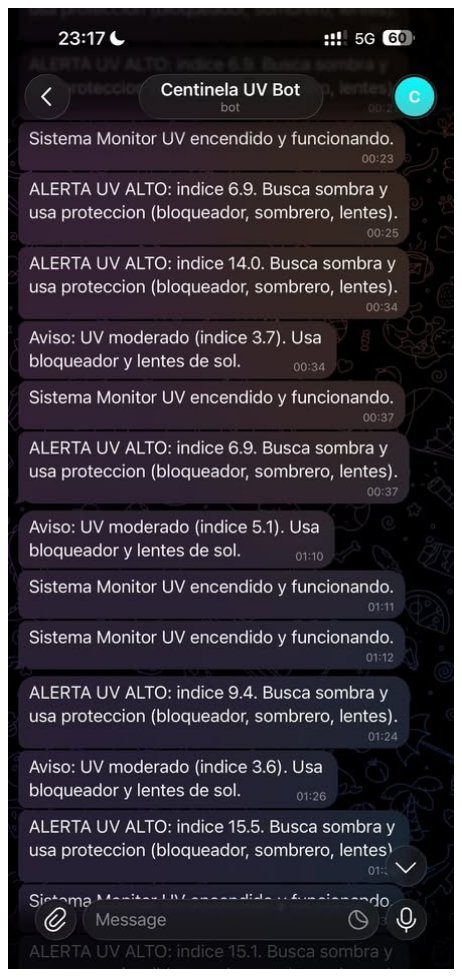
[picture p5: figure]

Figura 2. Alertas registradas durante las pruebas de simulación nocturna. Los índices altos (6.9, 14.0, 15.5) no corresponden a radiación solar: el sensor estaba expuesto a una fuente de luz artificial cercana. Los mensajes repetidos de "Sistema Monitor UV encendido" corresponden a reinicios del ESP32 (ver análisis de fallas).

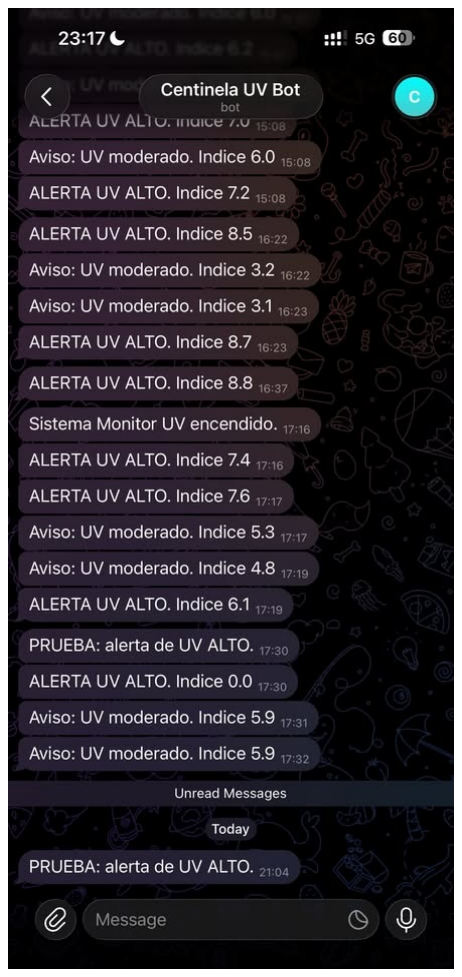
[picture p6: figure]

Figura 3. Alertas de las pruebas de la tarde, con radiación solar real (índices entre 3.1 y 8.8). A las 17:30 se ve el modo demostración: el mensaje PRUEBA: alerta de UV ALTO. seguido de ALERTA UV ALTO. Indice 0.0, porque el modo fuerza el estado sin medir.

Mensajes representativos:

Hora | Mensaje del bot | Tipo de prueba
15:08 | ALERTA UV ALTO. Indice 7.0 | Real (tarde con sol)
15:08 | ALERTA UV ALTO. Indice 7.2 | Real
16:22 | Aviso: UV moderado. Indice 3.2 | Real

16:37 | ALERTA UV ALTO. Indice 8.8 | Real
17:19 | Aviso: UV moderado. Indice 4.8 | Real
17:30 | PRUEBA: alerta de UV ALTO. | Modo demostración
17:30 | ALERTA UV ALTO. Indice 0.0 | Modo demostración (estado forzado)
00:25 | ALERTA UV ALTO: indice 6.9 | Simulación con luz artificial
00:34 | ALERTA UV ALTO: indice 14.0 | Simulación con luz artificial
01:24 | ALERTA UV ALTO: indice 9.4 | Simulación con luz artificial
21:04 | PRUEBA: alerta de UV ALTO. | Modo demostración

Lo que muestran estos resultados:

El LED y el mensaje siempre coincidieron con el nivel calculado: verde bajo 3.0, amarillo entre 3.0 y 5.9, rojo sobre 6.0.
El sistema no repite la alerta mientras el nivel se mantiene: solo avisa cuando el nivel cambia. En las capturas se ve que entre dos alertas de UV ALTO siempre hubo un descenso previo de nivel.
Los índices altos registrados de madrugada no son radiación solar: son simulaciones con una fuente de luz artificial. Las anotamos como tales para no confundir simulación con medición.
Los mensajes que empiezan con PRUEBA: corresponden al modo demostración, en el que el sistema fuerza el estado ALTO durante 8 segundos sin medir.

### 6. Resultados — Pruebas 4 y 6 (persistencia y dashboard)

El Monitor Serial mostró Dashboard HTTP: 200 en cada envío, lo que confirma que el servidor recibió y guardó la lectura. Al apagar el ESP32 y volver a abrir el dashboard desde otro dispositivo, las lecturas anteriores seguían disponibles: los datos persisten más allá de la sesión, que es justamente lo que distingue un sistema IoT de un simple monitor serial.

El dashboard mostró en todo momento el mismo valor que el Monitor Serial, con la recomendación de protección correspondiente al nivel y el gráfico del día con máximo, mínimo y promedio.

### 7. Análisis de fallas encontradas

Falla | Causa | Solución aplicada
Las lecturas saltaban de un segundo a otro (por ejemplo entre 0 y 1,2) aunque las condiciones no cambiaran | Ruido normal del ADC y del sensor, sobre todo con poca luz | El firmware toma 5 lecturas seguidas y las promedia antes de mostrar el valor. Si quisiéramos afinarlo más, podríamos aumentar la cantidad de muestras
Un mensaje decía "Aviso: UV moderado. Indice 6.0", aunque 6.0 debería ser nivel ALTO | El valor real era 5,95: la clasificación usa el número completo, pero el mensaje lo imprime redondeado a un decimal | Es un problema de presentación, no de lógica. La solución sería mostrar dos decimales o clasificar sobre el valor ya redondeado
Se repitió varias veces el mensaje "Sistema Monitor UV encendido" en pocos minutos | El ESP32 se reiniciaba. Lo atribuimos a caídas de tensión cuando el módulo WiFi transmite y la batería está baja | Probamos alimentando desde el Li-Po Rider Pro con la batería cargada, y los reinicios desaparecieron
El modo demostración envía "ALERTA UV ALTO. Indice 0.0" | La función revisarPrueba() fuerza el nivel a ALTO pero el índice sigue siendo el medido | No es un error de medición, es el comportamiento esperado del modo demo. Lo declaramos explícitamente para no confundirlo con una medición real

### 8. Validación contra el problema original

En el Avance 1 identificamos que las personas que pasan tiempo al aire libre no tienen una forma directa de saber cuándo la radiación UV es alta y deben protegerse.

Las pruebas muestran que Centinela UV entrega exactamente esa información:

1. Captura. La Prueba 1 demuestra que el sensor mide radiación real: se mantiene cerca de cero cuando hay poca luz y sube cuando aumenta.
2. Información. El sistema no muestra un voltaje crudo: lo convierte en un índice UV y lo clasifica en tres niveles asociados a una recomendación concreta de protección.
3. Decisión. El usuario recibe esa recomendación por tres vías con distinto alcance: el LED (para quien está al lado del dispositivo), el dashboard (para revisar el día) y la alerta de Telegram (para enterarse aunque no esté mirando nada).

La evidencia de Telegram es la más directa: durante las pruebas de la tarde, el bot avisó automáticamente cuando el índice cruzó 3.0 y cuando superó 6.0. Ese aviso, llegando al celular sin que el usuario haga nada, es justo la información que faltaba en el problema que planteamos.

El ciclo IoT queda cerrado:

El dispositivo captura datos → genera información → permite tomar decisiones

### 9. Conclusión y mejoras futuras

Centinela UV cumple el objetivo del proyecto: mide radiación ultravioleta real, la guarda, la muestra y avisa cuando hay riesgo.

Las limitaciones que reconocemos, y que serían el siguiente paso:

Calibrar el sensor contra un medidor UV de referencia. Hoy usamos la relación aproximada de la hoja de datos del ML8511, así que el valor absoluto puede tener error aunque la tendencia sea correcta.
Validar con sol de mediodía, para confirmar los umbrales altos con radiación real y no solo con luz artificial.
Guardar las lecturas localmente cuando no hay WiFi, y enviarlas al recuperar la conexión.
Limpiar los campos temp y hum que el firmware envía siempre en 0 y que quedaron de una versión anterior del proyecto. Medir el nivel de batería para avisar cuando quede poca carga.

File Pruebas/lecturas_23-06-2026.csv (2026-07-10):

fecha_hora | indice_uv | nivel | fase
2026-06-23 18:05:49 | 0.1 | BAJO | ambiente
2026-06-23 18:05:51 | 0.2 | BAJO | ambiente
2026-06-23 18:05:53 | 0.1 | BAJO | ambiente
2026-06-23 18:05:55 | 0.2 | BAJO | ambiente
2026-06-23 18:05:57 | 0.2 | BAJO | ambiente
2026-06-23 18:05:59 | 0.1 | BAJO | ambiente
2026-06-23 18:06:02 | 0.4 | BAJO | ambiente
2026-06-23 18:06:04 | 0.8 | BAJO | ambiente
2026-06-23 18:06:07 | 0.7 | BAJO | ambiente
2026-06-23 18:06:08 | 0.6 | BAJO | ambiente
2026-06-23 18:06:11 | 0.7 | BAJO | ambiente
2026-06-23 18:06:12 | 0.6 | BAJO | ambiente
2026-06-23 18:06:15 | 0.0 | BAJO | ambiente
2026-06-23 18:06:16 | 0.5 | BAJO | ambiente
2026-06-23 18:06:19 | 0.5 | BAJO | ambiente
2026-06-23 18:06:20 | 0.3 | BAJO | ambiente
2026-06-23 18:06:23 | 0.0 | BAJO | ambiente
2026-06-23 18:06:24 | 0.1 | BAJO | ambiente
2026-06-23 18:06:27 | 0.0 | BAJO | ambiente
2026-06-23 18:06:28 | 0.0 | BAJO | ambiente
2026-06-23 18:06:31 | 0.0 | BAJO | ambiente
2026-06-23 18:06:32 | 0.6 | BAJO | ambiente
2026-06-23 18:06:34 | 0.2 | BAJO | ambiente
2026-06-23 18:06:36 | 0.2 | BAJO | ambiente
2026-06-23 18:06:38 | 0.3 | BAJO | ambiente
2026-06-23 18:06:40 | 0.3 | BAJO | ambiente
2026-06-23 18:06:42 | 0.2 | BAJO | ambiente
2026-06-23 18:06:44 | 0.7 | BAJO | ambiente
2026-06-23 18:06:46 | 0.6 | BAJO | ambiente
2026-06-23 18:06:48 | 1.0 | BAJO | ambiente
2026-06-23 18:06:50 | 0.8 | BAJO | ambiente
2026-06-23 18:06:53 | 0.4 | BAJO | ambiente
2026-06-23 18:06:54 | 1.2 | BAJO | ambiente
2026-06-23 18:06:57 | 0.9 | BAJO | ambiente
2026-06-23 18:06:58 | 0.4 | BAJO | ambiente
2026-06-23 18:07:00 | 0.3 | BAJO | ambiente
2026-06-23 18:07:02 | 0.0 | BAJO | ambiente
2026-06-23 18:07:05 | 0.5 | BAJO | ambiente
2026-06-23 18:07:06 | 0.3 | BAJO | ambiente
2026-06-23 18:07:08 | 0.4 | BAJO | ambiente
2026-06-23 18:07:10 | 0.4 | BAJO | ambiente
2026-06-23 18:07:13 | 0.3 | BAJO | ambiente
2026-06-23 18:07:14 | 0.4 | BAJO | ambiente
2026-06-23 18:07:17 | 0.6 | BAJO | ambiente
2026-06-23 18:07:19 | 0.9 | BAJO | ambiente
2026-06-23 18:07:20 | 0.1 | BAJO | ambiente
2026-06-23 18:07:22 | 0.0 | BAJO | ambiente
2026-06-23 18:07:25 | 0.0 | BAJO | ambiente
2026-06-23 18:07:27 | 0.0 | BAJO | ambiente
2026-06-23 18:07:29 | 0.3 | BAJO | ambiente
2026-06-23 18:07:30 | 0.1 | BAJO | ambiente
2026-06-23 18:07:36 | 0.0 | BAJO | ambiente
2026-06-23 18:07:37 | 0.0 | BAJO | ambiente
2026-06-23 18:07:45 | 0.0 | BAJO | ambiente
2026-06-23 18:07:48 | 0.3 | BAJO | ambiente
2026-06-23 18:07:50 | 2.3 | BAJO | exposicion
2026-06-23 18:07:52 | 3.9 | MODERADO | exposicion

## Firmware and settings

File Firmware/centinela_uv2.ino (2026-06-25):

/*
  =====================================================================
  Monitoreo UV - ESP32-S3 + Hostinger + Telegram
  Proyecto: Centinela UV
  =====================================================================
*/

#include <WiFi.h>
#include <WiFiClientSecure.h>
#include <HTTPClient.h>

// ------------------- WIFI -------------------
const char* WIFI_SSID = "iPhone de Leo";
const char* WIFI_PASS = "123456789";

// ------------------- SERVIDOR HOSTINGER -------------------
const char* SERVIDOR  = "https://lightskyblue-zebra-707371.hostingersite.com/guardar.php";
const char* TEST_URL  = "https://lightskyblue-zebra-707371.hostingersite.com/test.php";
const char* CLAVE_API = "uv-grupo5-2026";

// Envía a Hostinger cada 3 segundos
const unsigned long INTERVALO_ENVIO = 3000;

// ------------------- TELEGRAM -------------------
const char* TG_TOKEN  = "8861657158:AAEg2c3pC8nNyDoterQ6hZ82UYEzgJWsybA";
const char* TG_CHATID = "8648240921";

const unsigned long COOLDOWN_TG = 30UL * 1000UL;   // 30 s (modo demo; normal: 5UL * 60UL * 1000UL)

// ------------------- PINES -------------------
const int PIN_UV = 4;   // OUT del sensor (GPIO4, ADC)

// Ojo: dejo estos pines como los tenías en tu código.
// Si tu LED está conectado a GPIO5, GPIO6 y GPIO7, cámbialos aquí.
const int PIN_R  = 40;
const int PIN_G  = 39;
const int PIN_B  = 38;

const bool ANODO_COMUN = false;

// ------------------- VARIABLES -------------------
float uvIntensity = 0.0;
float temperatura = 0.0;
float humedad = 0.0;

String nivel = "BAJO";
String nivelAnterior = "BAJO";

unsigned long ultimoEnvio = 0;
unsigned long ultimoTgMod = 0;
unsigned long ultimoTgAlto = 0;
unsigned long pruebaHasta = 0;

// ------------------- FUNCIONES -------------------
float mapFloat(float x, float in_min, float in_max, float out_min, float out_max) {
  return (x - in_min) * (out_max - out_min) / (in_max - in_min) + out_min;
}

void setColor(bool r, bool g, bool b) {
  if (ANODO_COMUN) {
    r = !r;
    g = !g;
    b = !b;
  }

  digitalWrite(PIN_R, r);
  digitalWrite(PIN_G, g);
  digitalWrite(PIN_B, b);
}

float leerUV() {
  long suma = 0;

  for (int i = 0; i < 5; i++) {
    suma += analogRead(PIN_UV);
    delay(1);
  }

  float promedio = suma / 5.0;
  float voltaje  = promedio * (3.3 / 4095.0);

  // Conversión aproximada del GY-ML8511
  float uv = mapFloat(voltaje, 0.99, 2.8, 0.0, 15.0);

  if (uv < 0) uv = 0;
  if (uv > 20) uv = 20;

  return uv;
}

void conectarWiFi() {
  if (WiFi.status() == WL_CONNECTED) return;

  WiFi.mode(WIFI_STA);
  WiFi.begin(WIFI_SSID, WIFI_PASS);

  Serial.print("Conectando a WiFi: ");
  Serial.println(WIFI_SSID);

  unsigned long inicio = millis();

  while (WiFi.status() != WL_CONNECTED && millis() - inicio < 20000) {
    delay(500);
    Serial.print(".");
  }

  Serial.println();

  if (WiFi.status() == WL_CONNECTED) {
    Serial.print("WiFi conectado. IP: ");
    Serial.println(WiFi.localIP());
  } else {
    Serial.println("No se pudo conectar al WiFi.");
    Serial.println("Revisa hotspot, clave y compatibilidad 2.4 GHz.");
  }
}

// Envía la lectura al dashboard usando POST
void enviarDato() {
  if (WiFi.status() != WL_CONNECTED) {
    Serial.println("WiFi desconectado. Reintentando...");
    conectarWiFi();
    return;
  }

  WiFiClientSecure client;
  client.setInsecure();

  HTTPClient http;

  String cuerpo = "key=" + String(CLAVE_API) +
                  "&uv=" + String(uvIntensity, 1) +
                  "&temp=" + String(temperatura, 1) +
                  "&hum=" + String(humedad, 0);

  Serial.print("Enviando a Hostinger: ");
  Serial.println(cuerpo);

  http.begin(client, SERVIDOR);
  http.addHeader("Content-Type", "application/x-www-form-urlencoded");

  int codigo = http.POST(cuerpo);
  String respuesta = http.getString();

  Serial.print("Dashboard HTTP: ");
  Serial.println(codigo);

  Serial.print("Respuesta servidor: ");
  Serial.println(respuesta);

  http.end();
}

void enviarTelegram(String mensaje) {
  if (WiFi.status() != WL_CONNECTED) return;

  WiFiClientSecure client;
  client.setInsecure();

  HTTPClient http;

  mensaje.replace(" ", "%20");
  mensaje.replace("\n", "%0A");

  String url = "https://api.telegram.org/bot" + String(TG_TOKEN) +
               "/sendMessage?chat_id=" + String(TG_CHATID) +
               "&text=" + mensaje;

  http.begin(client, url);
  int codigo = http.GET();

  Serial.print("Telegram HTTP: ");
  Serial.println(codigo);

  http.end();
}

void revisarPrueba() {
  if (WiFi.status() != WL_CONNECTED) return;

  WiFiClientSecure client;
  client.setInsecure();

  HTTPClient http;
  http.begin(client, TEST_URL);

  int codigo = http.GET();

  if (codigo == 200) {
    String resp = http.getString();
    resp.trim();

    if (resp == "1") {
      pruebaHasta = millis() + 8000;
      enviarTelegram("PRUEBA: alerta de UV ALTO.");
    }
  }

  http.end();
}

// ------------------- SETUP -------------------
void setup() {
  Serial.begin(115200);
  delay(1000);

  Serial.println();
  Serial.println("Iniciando Centinela UV...");

  pinMode(PIN_R, OUTPUT);
  pinMode(PIN_G, OUTPUT);
  pinMode(PIN_B, OUTPUT);

  analogReadResolution(12);
  analogSetPinAttenuation(PIN_UV, ADC_11db);

  setColor(0, 0, 0);

  conectarWiFi();

  if (WiFi.status() == WL_CONNECTED) {
    enviarTelegram("Sistema Monitor UV encendido.");
  }
}

// ------------------- LOOP -------------------
void loop() {
  static unsigned long tiempoMedicion = 0;

  if (millis() - tiempoMedicion > 120) {
    tiempoMedicion = millis();

    uvIntensity = leerUV();

    if (uvIntensity < 3.0) {
      nivel = "BAJO";
      setColor(0, 1, 0);   // verde
    } else if (uvIntensity < 6.0) {
      nivel = "MODERADO";
      setColor(1, 1, 0);   // amarillo
    } else {
      nivel = "ALTO";
      setColor(1, 0, 0);   // rojo
    }

    if (millis() < pruebaHasta) {
      nivel = "ALTO";
      setColor(1, 0, 0);
    }

    Serial.print("UV: ");
    Serial.print(uvIntensity, 2);
    Serial.print(" -> ");
    Serial.println(nivel);

    if (nivel == "MODERADO" && nivelAnterior == "BAJO" &&
        (ultimoTgMod == 0 || millis() - ultimoTgMod > COOLDOWN_TG)) {
      enviarTelegram("Aviso: UV moderado. Indice " + String(uvIntensity, 1));
      ultimoTgMod = millis();
    }

    if (nivel == "ALTO" && nivelAnterior != "ALTO" &&
        (ultimoTgAlto == 0 || millis() - ultimoTgAlto > COOLDOWN_TG)) {
      enviarTelegram("ALERTA UV ALTO. Indice " + String(uvIntensity, 1));
      ultimoTgAlto = millis();
    }

    nivelAnterior = nivel;
  }

  if (millis() - ultimoEnvio > INTERVALO_ENVIO) {
    ultimoEnvio = millis();
    enviarDato();
  }

  static unsigned long ultimaPrueba = 0;

  if (millis() - ultimaPrueba > 6000) {
    ultimaPrueba = millis();
    revisarPrueba();
  }
}

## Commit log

2026-06-24 Monitoreo de pruebas
2026-06-25 .
    Removed cables/protoboard entry from connections table.
2026-06-25 Enhance decision section with web access details.
    Updated the decision section to include details about accessing the web page and sharing Wi-Fi with the device.
